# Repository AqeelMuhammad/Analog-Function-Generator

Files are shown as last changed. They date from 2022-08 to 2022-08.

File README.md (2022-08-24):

# Analog-Function-Generator

* Function generators are commonly used to generate analog waveforms (like sine waves, square waves, sawtooth waves etc.) in a variety of applications, such as sweep generation, AM/FM generation and Phase Locked Loops (PLLs). 
* Some of the popular analog ICs used in the past were MAX038, XR2206 and NTE864. Now they have been mostly replaced with chips using Direct Digital Synthesis (AD9850 DDS signal generator module). 
* Function generators can usually change their waveform frequency precisely among a wide range of values (0.1 Hz to 1 MHz). Furthermore, they can even change their amplitudes and average DC values. In some sensitive applications, capability of a function generator to create a clean, noise-free waveform becomes 
extremely important. 
* This repo is about an analog circuit using transistors and op-amps which can generate sine waves, square waves (with variable duty cycle), sawtooth waves and triangular waves.
* The project was done by a team of 4 undergraduates at the Department of Electronic and Telecommunication Engineering, University of Moratuwa, Sri Lanka for UOM's EN2090 - Laboratory Practice - II module.

### Contributors

1. [Muhammad Aqeel](https://github.com/AqeelMuhammad)
1. [yomali lokugama](https://github.com/lokugama-vyn)
1. [Tharushi Pinimuthu](https://github.com/)
1. [Sanduni Kaushalya](https://github.com/)

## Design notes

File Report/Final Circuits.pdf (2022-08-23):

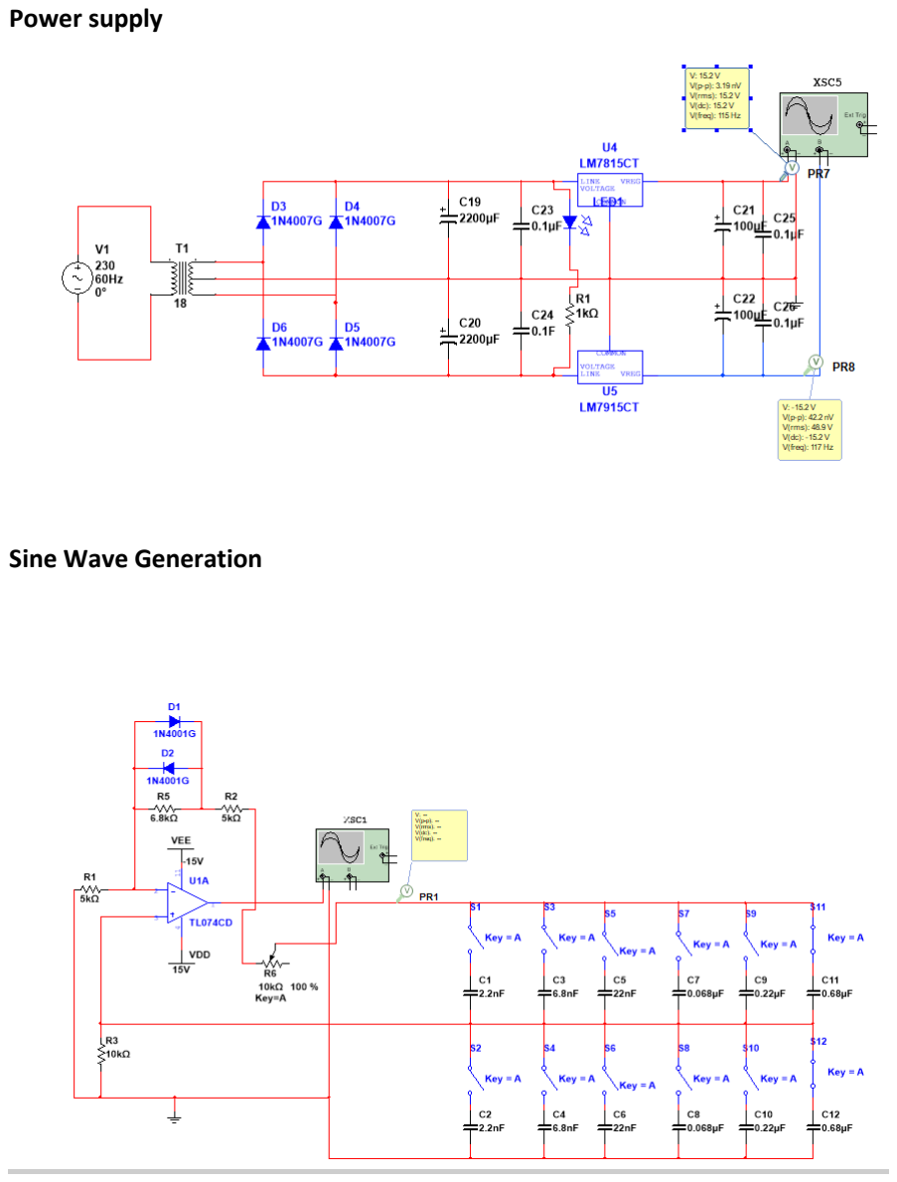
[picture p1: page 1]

Power supply

Sine Wave Generation

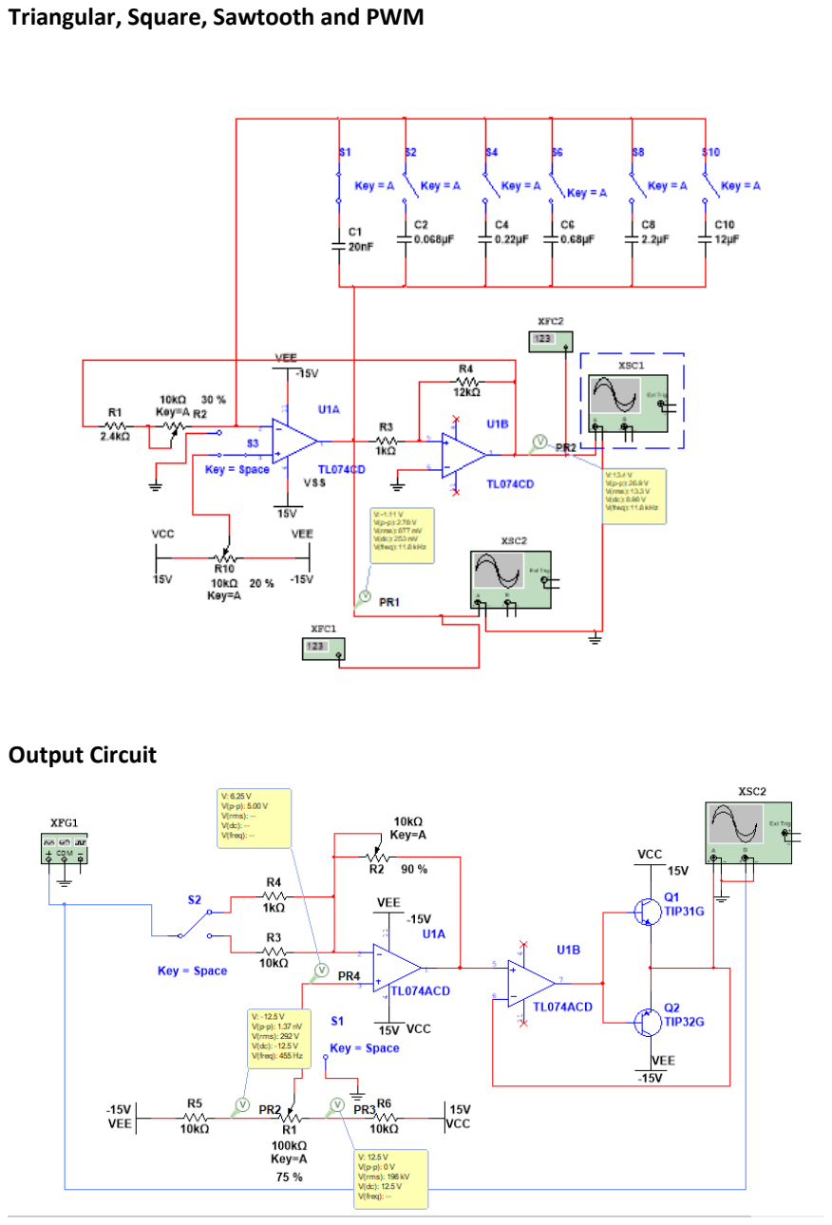
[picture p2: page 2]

Triangular, Square, Sawtooth and PWM

Output Circuit

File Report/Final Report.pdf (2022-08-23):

Department of Electronic and Telecommunication Engineering

University of Moratuwa

EN – 2090 Laboratory practice II

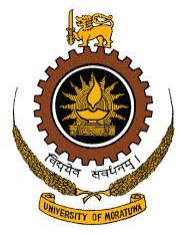
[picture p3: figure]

## ANALOG FUNCTION GENERATOR

GROUP 20

AQEEL T.M. | 180039C
KAUSHALYA P.A.S. | 180320F
LOKUGAMA V.Y.N. | 180359G
PATHIRANA T.P.W. | 180453N

This is submitted as a partial fulfillment for the module EN 2090: Laboratory Practice II Department of Electronic and Telecommunication Engineering University of Moratuwa

ABSTRACT

Function generator is an electronic device which generates various types of electrical waveforms over a broad range of frequencies. These devices can be used to generate waves with variable frequencies, amplitudes, offsets, and duty cycles for various experimental design purposes. Today most of the function generators are made using digital electronics components and these devices costs around $1000. This report talks about the overview of a signal generator, how to generate function using analog electronics, and changing its characteristics like waveform, modulation, frequency, and amplitude voltage.

CONTENTS

1. INTRODUCTION ------------------------------------------------------------------------------------------4
2. ELECTRONIC DESIGN ----------------------------------------------------------------------------------4

2.1 Design Specifications --------------------------------------------------------------------------------4

2.2 Waveform Generation-------------------------------------------------------------------------------4

2.2.1 Square Wave--------------------------------------------------------------------------------- 4

2.2.2 Triangular Wave---------------------------------------------------------------------------- 5

2.2.3 Sawtooth Wave ------------------------------------------------------------------------------ 5

2.2.4 PWM Wave ---------------------------------------------------------------------------------- 5

2.2.5 Sine Wave ------------------------------------------------------------------------------------ 6

2.3 Other Circuits -----------------------------------------------------------------------------------------6

2.3.1 DC shift --------------------------------------------------------------------------------------- 6

2.3.2 Push Pull Amplifier------------------------------------------------------------------------- 6

Class A -----------------------------------------------------------------------------------------------------6

Class B -----------------------------------------------------------------------------------------------------6

Class AB ---------------------------------------------------------------------------------------------------7

2.3.3 Power Supply Circuit ---------------------------------------------------------------------- 7

3. SIMULATIONS---------------------------------------------------------------------------------------------7

3.1 Sine Wave-----------------------------------------------------------------------------------------------7

3.2 Triangular, Square, Sawtooth, & PWM--------------------------------------------------------8

3.3 DC Shift & Amplification --------------------------------------------------------------------------8

4. CALCULATIONS ------------------------------------------------------------------------------------------9

4.1 Triangular, Sawtooth and Square Wave Calculation---------------------------------------9

4.2 Sine Wave Calculation ------------------------------------------------------------------------------9

4.2.1 Wein Bridge Oscillator ------------------------------------------------------------------ 10

5. OP AMP SELECTION----------------------------------------------------------------------------------- 11
6. ROTARY SWITCH -------------------------------------------------------------------------------------- 11
7. SCHEMATIC DESIGNS-------------------------------------------------------------------------------- 12
8. LAYOUTS-------------------------------------------------------------------------------------------------- 12
9. REFERENCES -------------------------------------------------------------------------------------------- 14

### 1. INTRODUCTION

The | function | generator | can | generate
square, triangle, sawtooth, PWM and sine waveforms. Function generators can usually change their waveform frequency precisely among a wide range of values. Furthermore, they can even change their amplitudes and average DC values.

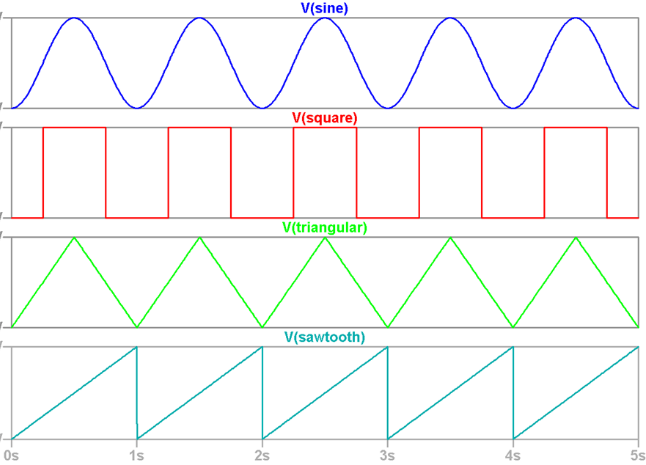
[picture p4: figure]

Figure 1 - Different types of waveforms

Some applications of function generator are sweep generation, AM/FM generation and Phase Locked Loops (PLLs).

In this report, we describe how we are going to build an analog circuit using transistors and op-amps and how we are going to change the frequencies and the amplitudes of the waveforms.

### 2. ELECTRONIC DESIGN

### 2.1 Design Specifications

In this project, we will fulfill the following specifications.

1. Function generator should be able generate sine, square, pulse width modulation, sawtooth, and triangular waves.
2. The output amplitude should be variable from 0V to 10V.
3. The output frequency should be variable from 20 Hz to 20000 Hz.
4. It should be able to drive at least a 50 Ohm load without significant waveform distortion or amplitude reduction.
5. PWM waveform should have a variable pulse width (1% to 99%).
6. The function generator should be able to give a DC shift to the waves.

### 2.2 Waveform Generation

2.2.1 Square Wave

The square wave as well as the triangular waves are combined together, which means that the output of one circuit acts as input of the other. The square wave was just the result of the comparator property of the Op-Amp used. The triangular wave was sent through the inverting input and a threshold voltage was set with the help of a feedback resistor and an input resistor. To change the frequency of the wave we are going to use a potentiometer in the place of R3 with a fixed resistor.

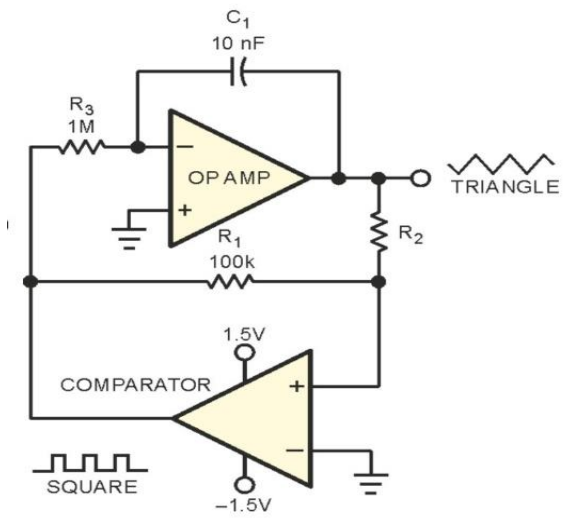
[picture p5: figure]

Figure 2 - Square & triangular waveform generating circuit

The solitary-comparator circuit uses a relaxation oscillator approach with the triangle approximation assuming an RC nature and by adding an integrator improves the triangle approximation. The circuit includes a hysteretic-feedback path as well as an RC or integrator feedback path comprising R3 and C1. The hysteretic-feedback path keeps changing the direction of the RC integrator and setting the new target voltage, and the RC integrator sets the rate of change toward the new target.

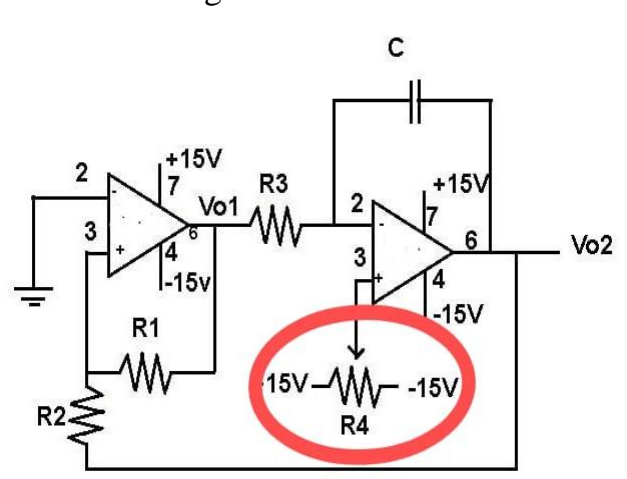
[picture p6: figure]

In the above circuit, we can calculate the frequency using the following equation.

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
(4 × R3 × C1)

So, we are planning to change the frequency of the waveform using R3 resistor and C1 capacitor fixing the resistors R1 & R2.

2.2.2 Triangular Wave

As shown in the figure 2 the integral Op-Amp is used in generate triangular wave from square wave. The square wave output was input to the Op-Amp with a capacitance and an input resistor value which makes the Op-Amp to act as a desired integrator. The frequency of the wave can be changed in the same way by changing the frequency of the square wave.

Figure 4- integrator

2.2.3 Sawtooth Wave

We plan to generate the sawtooth waveform from the same output pin where the triangular wave is generated. The only change made in the circuit is, if the non-inverting input of the

Op-Amp is set to ground triangular wave is generated whereas if that is set to a potentiometer with a varying voltage a sawtooth waveform is generated. The modification is given below.

2.2.4 PWM Wave

We plan to generate the PWM waveform from the triangular wave. A comparator is used to generate different duty cycles of PWM. We plan to give a reference voltage to inverting input at the same time we give the triangular wave to non-inverting input. If instantaneous voltage of the triangular wave is greater than the reference, output will be +Vs if less than reference, output will be -Vs. By changing the reference-voltage we give, we can change the duty cycle. For changing reference-voltage we plan to use a voltage divider circuit with a potentiometer.

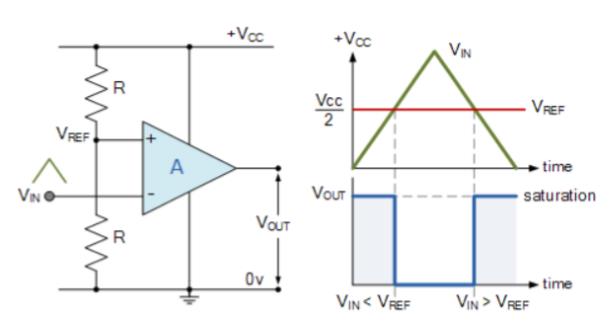
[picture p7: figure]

Figure 5 Comparator Circuit

Figure 3 - Sawtooth generation circuit

2.2.5 Sine Wave

To obtain the sine waveform, we plan to use the Wein bridge oscillator circuit. The circuit is stabilized for controlling the gain. The Wein bridge oscillator has two capacitors, of which the values should be equal to each other. The frequency range is selected using these capacitors, while the variable resistor is used to obtain a specific frequency within the selected range.

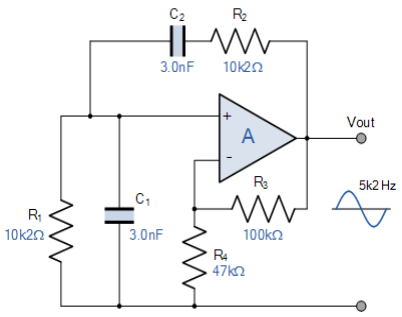
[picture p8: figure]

Figure 6 - Wein Bridge Oscillator

Hence, here is a frequency point where the maximum Vout can be occurred and it is known as oscillator resonance frequency(fr) At fr, Xc = R and phase difference between input and output is zero.

The circuit contains two RC pairs where in one R & C are in series and in the other the R & C are in parallel. Both the series and parallel RC combinations combined together to make a frequency dependent voltage divider. The output of the operational amplifier (op amp) is fed back to both the inputs of the op amp, through a feedback resistor to the inverting input and through the series RC combination to the non-inverting input. The whole combination generates a sine wave at the resonance frequency(fr), given by the equation,

fr =

1
2πRC

Fr -resonant frequency
R-Resistance
C- Capacitance
In this circuit, in series and parallel RC
combinations, | two | resistors | and | two
capacitors have to be of the same value.

### 2.3 Other Circuits

2.3.1 DC shift

We plan to add a DC offset to the generated waveform using an Op-Amp circuit. It is an inverting amplifier circuit. Input and a DC voltage is given to the inverting pin of the Op-Amp. DC voltage is controlled by the potentiometer.

2.3.2 Push Pull Amplifier

Class A
- One transistor always remains ON
- Distortions are minimum
- Amplified efficiency is 30%
- Same amount of load current to flow through even when there is no signal.

Class B
- The two identical transistors are connected in such a way that each transistor is operating per each half cycle.
- Efficiency is about 50%, greater than of class A
- Q point of the transistor is located at its cut off region

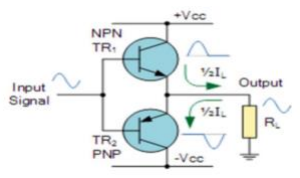
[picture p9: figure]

Figure 7 - Class B

Class AB
- The efficiency is about 50%
- Conduction angle is between 180 and 360
- Low crossover distortion
- In here both transistors are on between -0.7v and 0.7v
- High linearity like class A amplifier

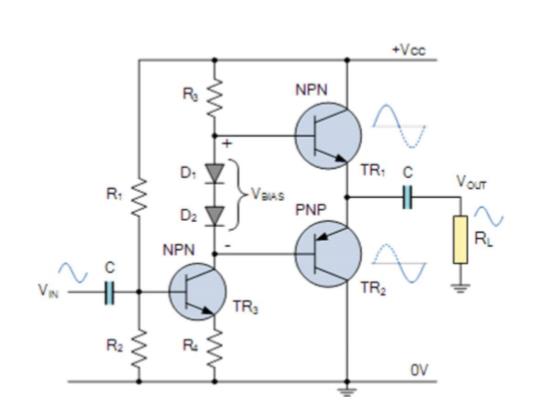
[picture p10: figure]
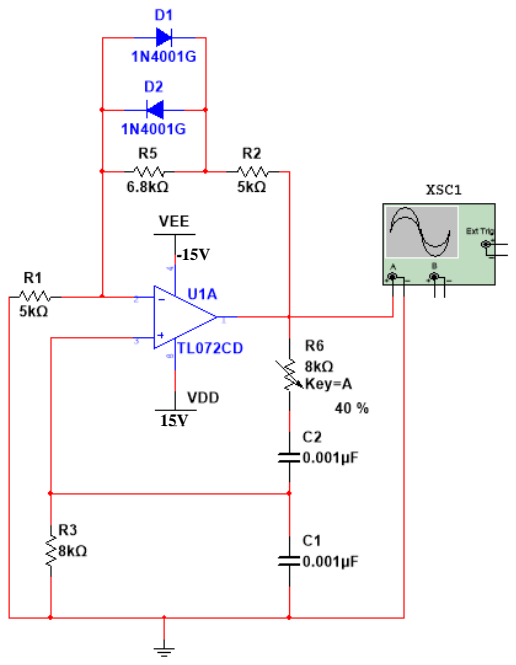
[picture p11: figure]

Figure 8 - Class AB

We are going to design the amplifier circuit in three stages.

Inverting amplifier stage -To obtain a variable amplitude
Voltage buffer stage - To maintain the stability
Push pull amplifier stage – To produce high current

2.3.3 Power Supply Circuit

We have to create +12V and -12V DC power supply to perform our expected task. Since the function generator is a laboratory equipment and it is used for a long time, we planned to supply the voltage using an AC power supply. We are going to use a stepdown transformer of 15V, a rectifier bridge and LM7812 and LM7912 regulators for this purpose.

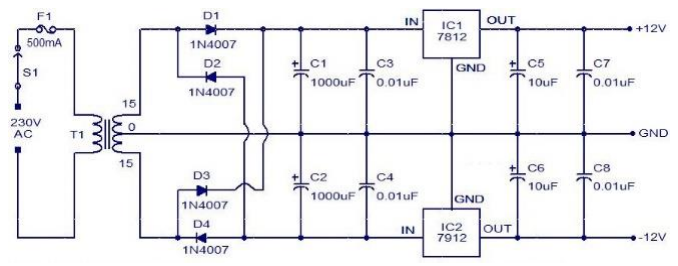
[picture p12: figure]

Figure 9 - Power Supply Circuit

### 3. SIMULATIONS

### 3.1 Sine Wave

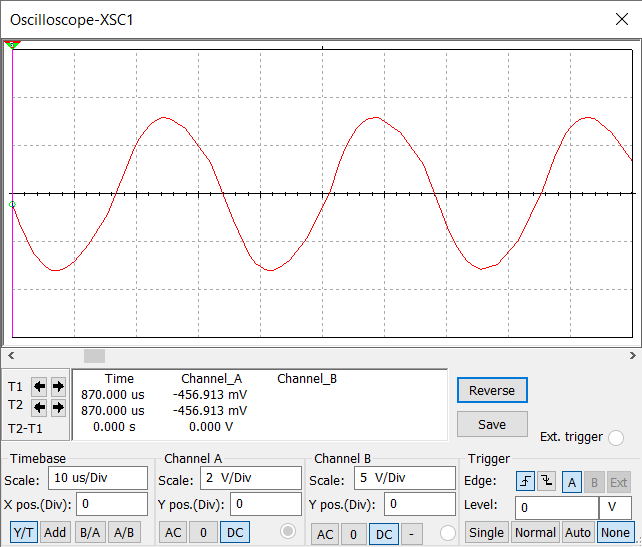
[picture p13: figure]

Figure 10 - Sine Wave Simulation

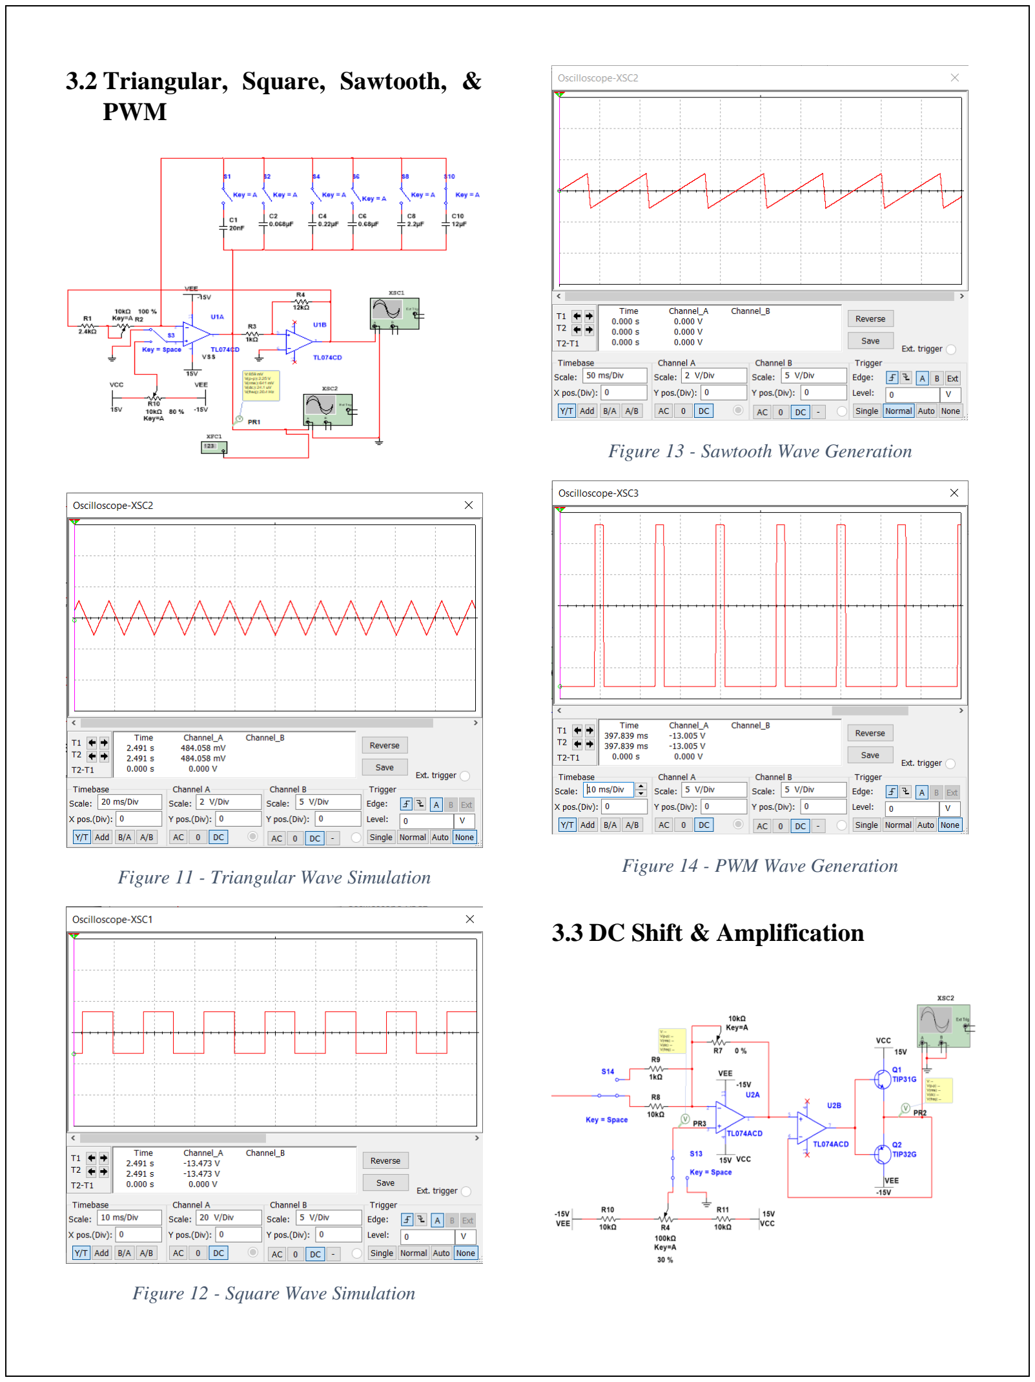
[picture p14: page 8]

### 3.2 Triangular, Square, Sawtooth, &

PWM

Figure 11 - Triangular Wave Simulation

Figure 12 - Square Wave Simulation

Figure 13 - Sawtooth Wave Generation

Figure 14 - PWM Wave Generation

### 3.3 DC Shift & Amplification

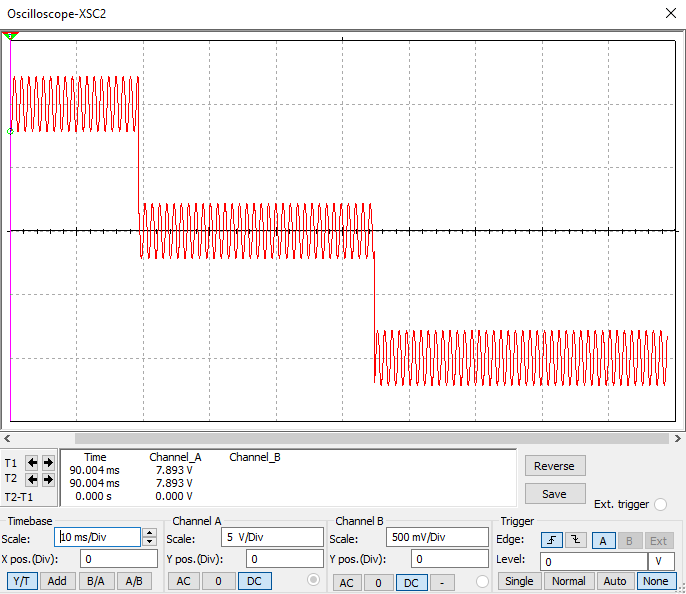
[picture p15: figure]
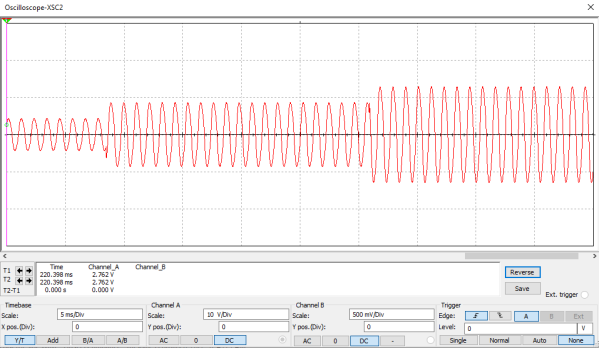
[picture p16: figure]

Figure 15 - shift Simulation

### 4. CALCULATIONS

### 4.1 Triangular, Sawtooth and Square

Wave Calculation

- For 20Hz,
R3 = 6.2kΩ | R2 = 2.4kΩ
R4 = 1kΩ | R5 = 12kΩ

20 =

12
1

×

| 1
4×(6200+2400)×C1

C1 = 17.44 µF

- For 20kHz,
R3 = 0kΩ | R2 = 2.4kΩ
R4 = 1kΩ | R5 = 12kΩ

20000 =

12
1

×

| 1
| 4×(2400)×C1

C1 = 0.0625 µF

### 4.2 Sine Wave Calculation

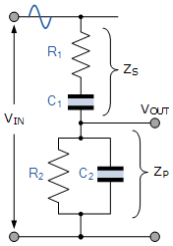
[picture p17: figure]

Figure 17 -Sine Wave Generation Circuit

For example, we can take R1=R2=12kΩ, C1=C2=3.9nF and the supply frequency f=3.4kHz.

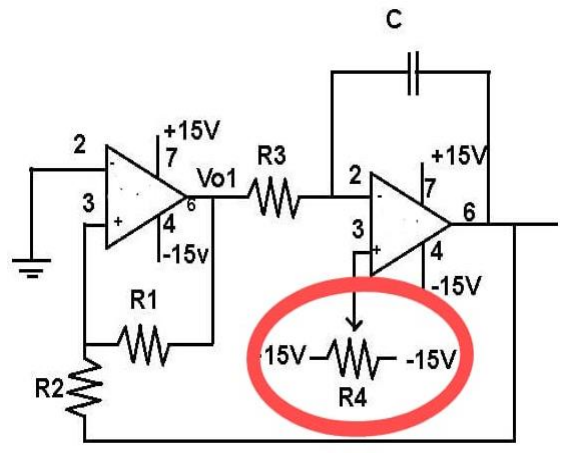
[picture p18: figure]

Figure 16 -Wave Form Generation Circuit

- For Series Combination

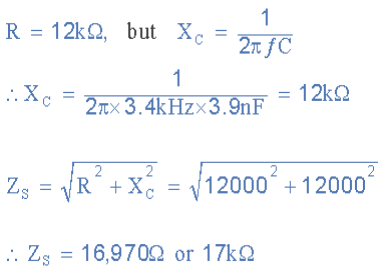
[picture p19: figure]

- For Parallel Combination

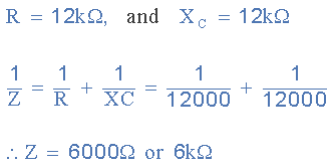
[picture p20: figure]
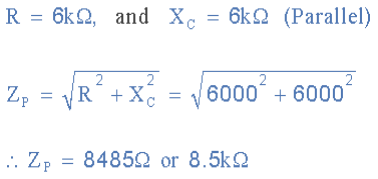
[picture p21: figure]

- Z Out of Voltage Divider
- Then,

Vout = Zout x Vin

Vout =

1
3

x Vin

Above values are used to show how 1/3 comes and We will change the resistor values for the circuit while we will be testing the circuits according to the results.

4.2.1 Wein Bridge Oscillator

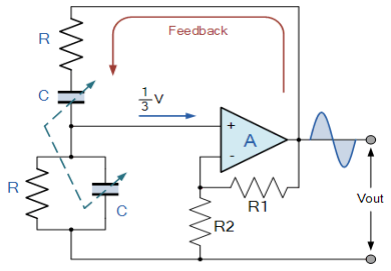
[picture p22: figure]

Figure 18- Wein Bridge Oscillator

[

To get the oscillation output, Av ≥ 3

fr =

1
2πRC

We have to vary the frequency from 20Hz-20000kHz. We have choose C1,C2 as 1nF to achieve maximum 20kHz frequency.

R =

1
2π × 20kHz × 1nF
= 7.957kΩ ≈ 8kΩ

We have choose C1,C2 value as 1uF to achieve minimum 20Hz frequency.

f =

1
2π × 8kHz × 1μF

= 19.89Hz ≈ 20Hz

To begin the sinusoidal oscillation Av ≥ 3; We Assumed R4 as 5kΩ. Then,

Output voltage gain of non-inverting amplifier (Av) = 1 +

R1
R2

=

Vout

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
R3 ≥ 10kΩ

We need to use some methods to be stabilizing the amplitude of the oscillations. If the voltage gain of the amplifier is too small the desired oscillation will decay and stop. If it is too large the output will saturate to the value of the supply rails and distort. We have used feedback diodes to stabilization of amplitude.

### 5. OP AMP SELECTION

When choosing an op amp, we must consider the main requirements. They are,

- Input offset voltage
- Input impedance
- Input leakage current
- Common mode rejection ratio
- Open loop gain
- Bandwidth
- Maximum output slew rate
- Output source and sink current limits
- Noise figure

But needed requirements differ from application to application. We want to find an op amp with better features for the function generator circuits. We choose TL072 and LM741 to generate waveforms.

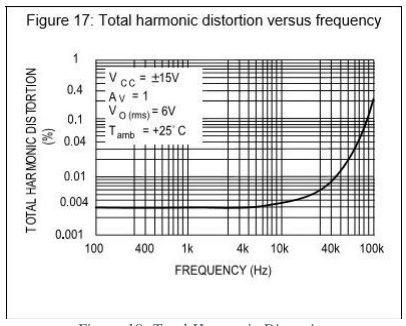
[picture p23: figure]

These two figures show how the noise input voltage and harmonic distortions change with respect to the frequency. Hence, both noise effect and harmonic distortions increase when frequency is increased. We have to change the frequency from 20Hz-20000Hz, and it is suitable to stop all scenarios that can generate noise as well as harmonic distortions. We choose TL072 on the fact of low noise and low harmonic distortions. There are number of noise sources within an op amp such as resistor noise, current noise, and KT/C noise. Reduction of resistors as well as covering the non-used pins of op-amps may help to reduce the noise effects and harmonic distortions.

### 6. ROTARY SWITCH

For the selection of different frequencies of the waveforms, and for the selection of the waveform. we are going to use rotary switches in our design. A rotary switch is a switch in which the contacts are changed when the spindle is rotated in either a clockwise or an anticlockwise direction. We

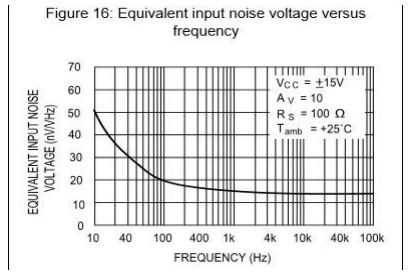
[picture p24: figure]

Figure 20 - Equivalent Input Noise Voltage

Figure 19 -Total Harmonic Distortion


are going to use 1 pole 12-way rotary switch for this purpose, and we can change the frequency values by changing the capacitor values.

Figure 21 -Rotary Switch

### 7. SCHEMATIC DESIGNS

### 8. LAYOUTS

Figure 22 – Sine Wave Schematic

Figure 23 – Sawtooth, Triangular, Square, & PWM Wave Schematic

Figure 24 – Output Circuit Schematic

Figure 25 – Power Supply Circuit Schematic

Figure 26 – Sawtooth, Triangular, Square, & PWM Wave 3D


Figure 28 – Sine Wave Layout

Figure 27 – Sawtooth, Triangular, Square, & PWM Wave 3D

Figure 29 – Sine Wave 3D

Figure 30 – Output Circuit Layout

Figure 31 – Output Circuit 3D

Figure 32 – Power Supply Circuit Layout

Figure 33 – Power Supply Circuit 3D

### 9. REFERENCES

https://www.instructables.com/id/Function-Generator/ (https://www.instructables.com/id/Function-Generator/)

https://www.watelectronics.com/squarewave-generator-circuit-using-op-amp/ (https://www.watelectronics.com/square-wave-generator-circuit-using-op-amp/)

https://www.radiolocman.com/shem/schematics.html?di=277157 (https://www.radiolocman.com/shem/schematics.html?di=277157)

http://www.circuitsgallery.com/2012/04/tria ngul ar-wave-generator-using-op-amp.html (http://www.circuitsgallery.com/2012/04/triangul%20ar-wave-generator-using-op-amp.html)

https://www.maximintegrated.com/en/design/technical-documents/appnotes/3/3846.html (https://www.maximintegrated.com/en/design/technical-documents/app-notes/3/3846.html)

https://www.electronicstutorials.ws/opamp/op-amp-comparator.html (https://www.electronics-tutorials.ws/opamp/op-amp-comparator.html)

https://electronics.stackexchange.com/questions/370739/how-to-add-dc-offset-and-gainto-a-given-signal (https://electronics.stackexchange.com/questions/370739/how-to-add-dc-offset-and-gain-to-a-given-signal)



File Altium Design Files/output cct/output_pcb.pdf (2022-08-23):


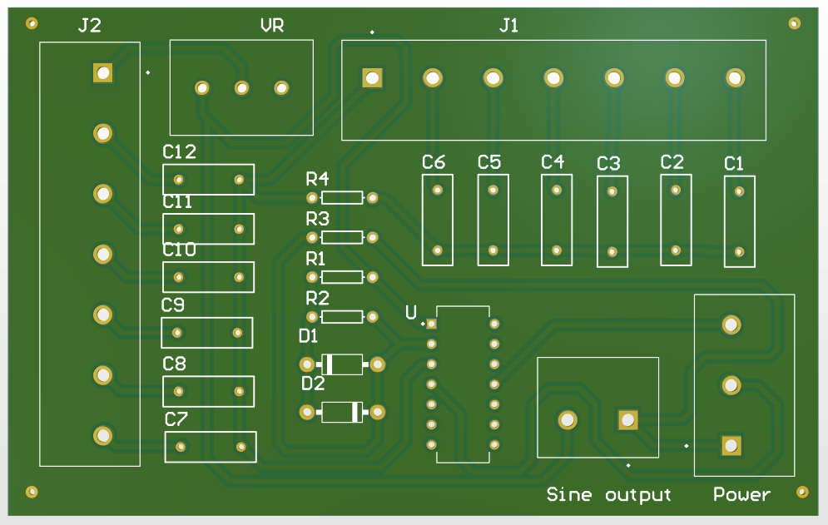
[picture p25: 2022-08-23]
Images/Altium Designs/sine 3d.PNG

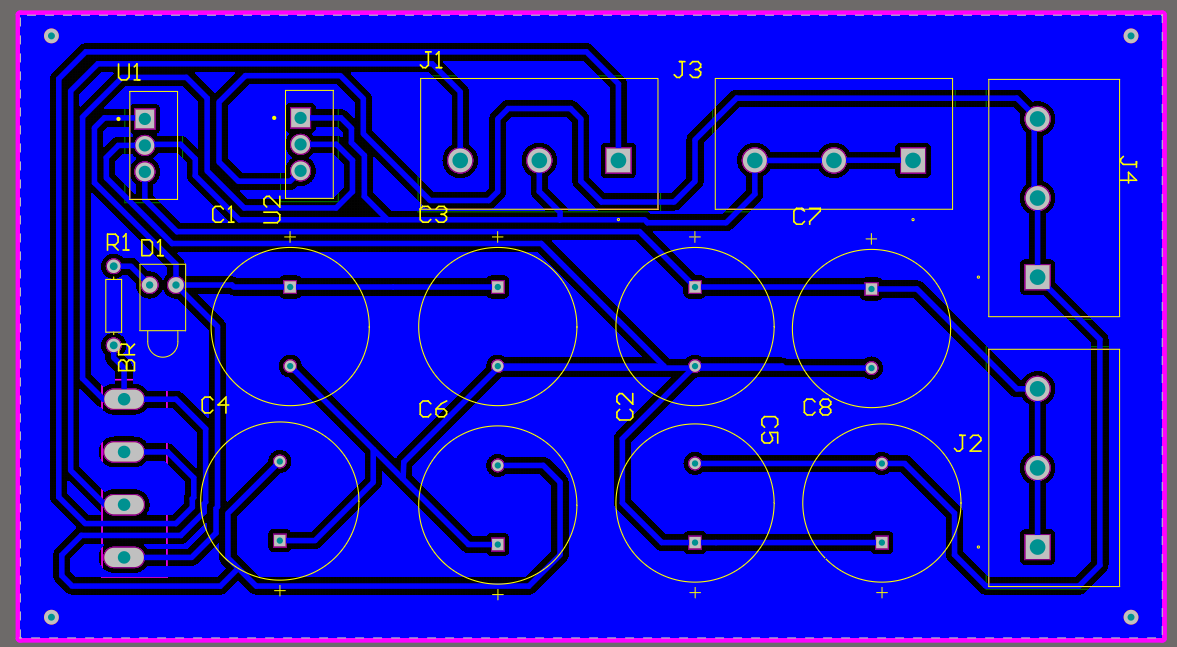
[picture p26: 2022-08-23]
Images/Altium Designs/power supply.PNG

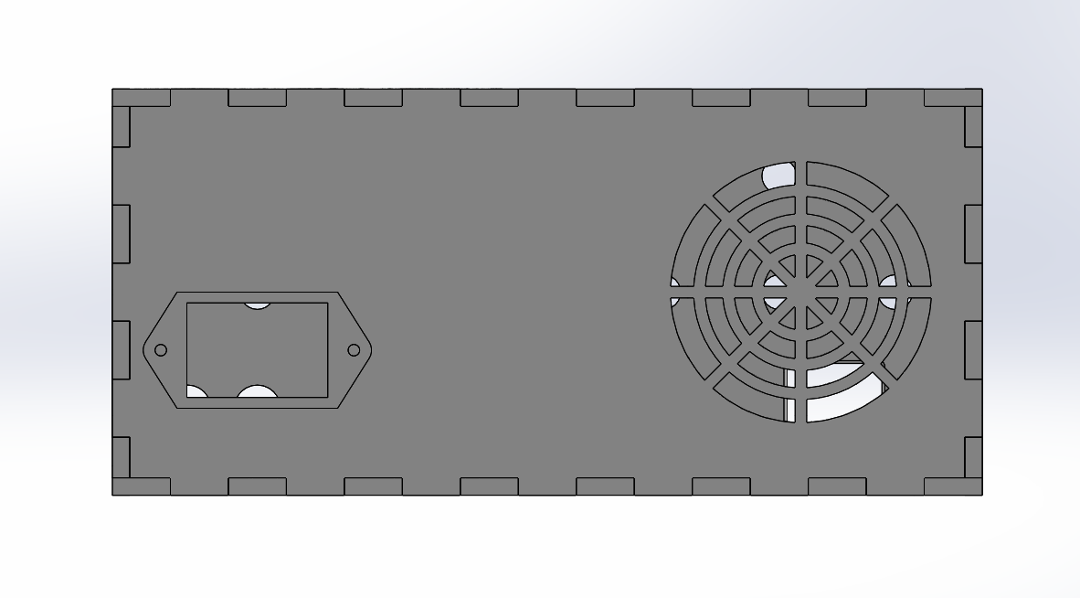
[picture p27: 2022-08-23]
Images/SolidWorks Designs/Final/Back.png

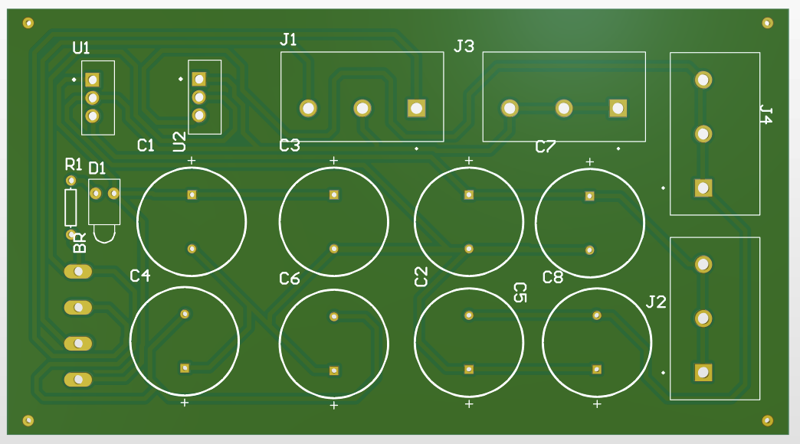
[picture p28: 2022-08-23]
Images/Altium Designs/power supply 3d.PNG

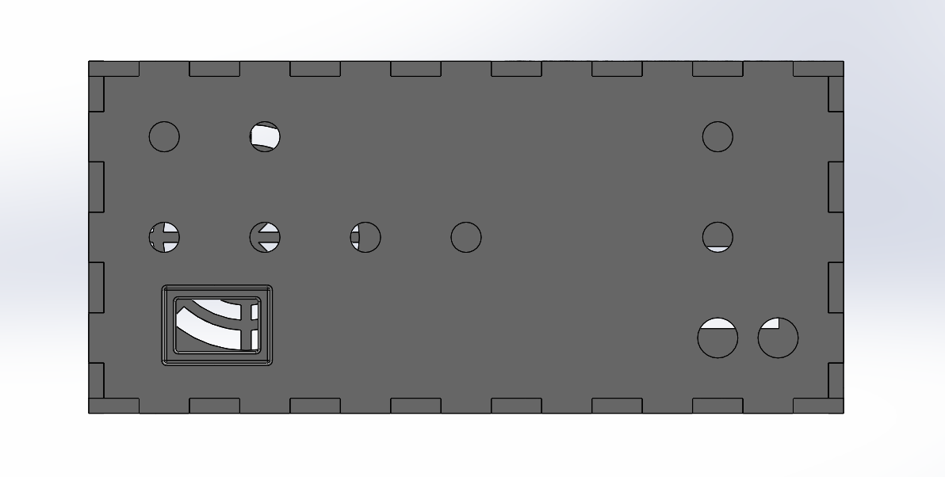
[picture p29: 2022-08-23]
Images/SolidWorks Designs/Final/Front.png

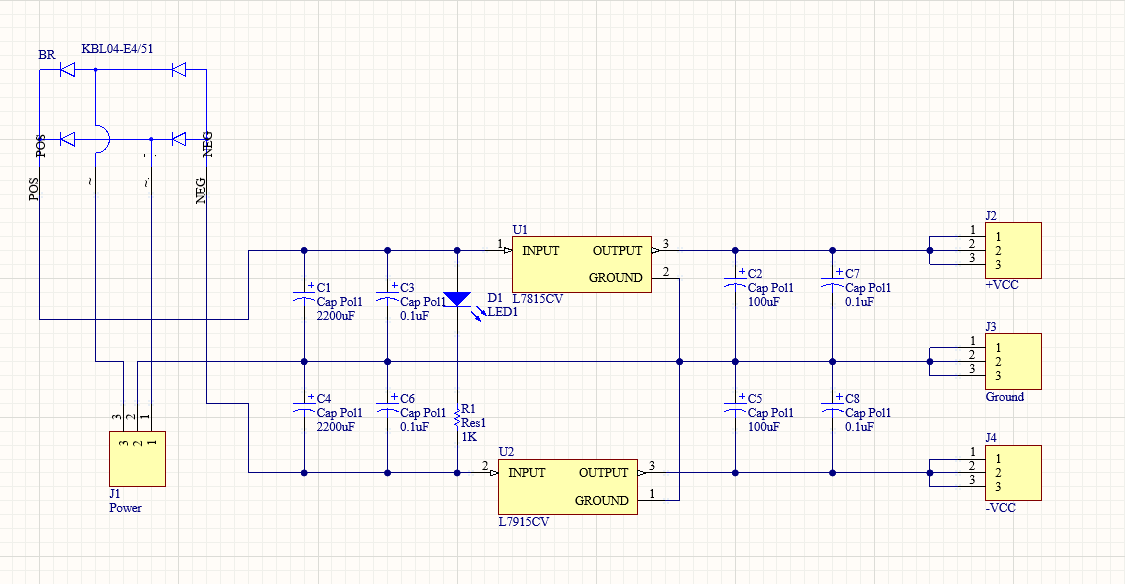
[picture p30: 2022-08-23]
Images/Altium Designs/power supply sch.PNG

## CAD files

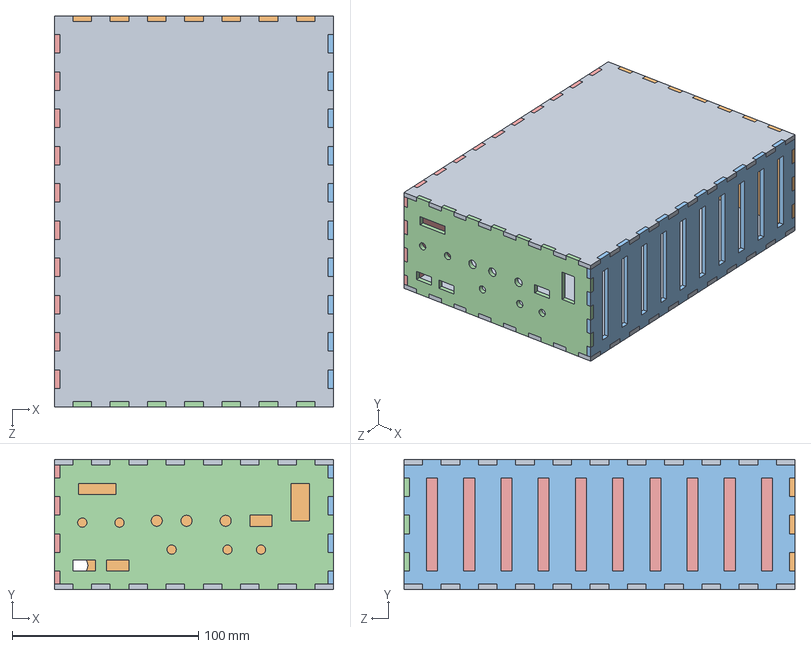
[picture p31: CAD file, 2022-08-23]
SolidWork Design Files/Assem2.SLDASM
150.0 x 70.0 x 210.0 mm

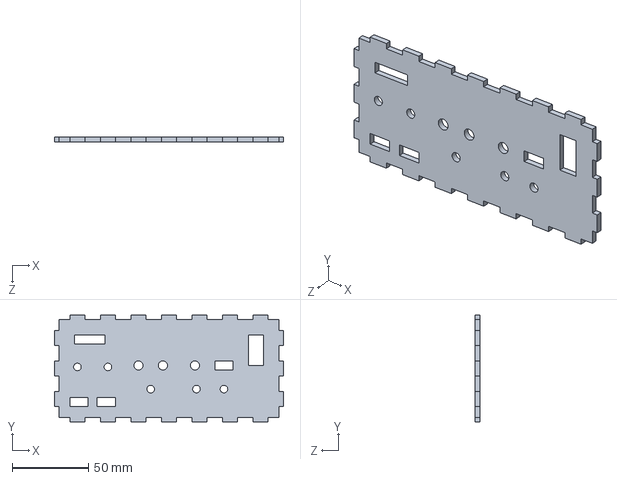
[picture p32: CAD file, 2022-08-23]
SolidWork Design Files/Part11.SLDPRT
150.0 x 70.0 x 3.00 mm

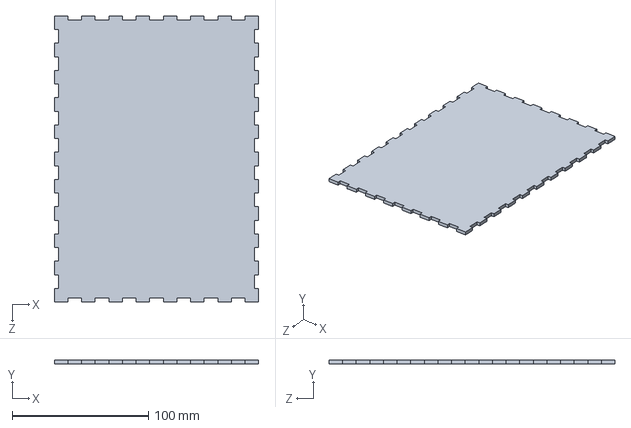
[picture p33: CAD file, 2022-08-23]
SolidWork Design Files/Part2.SLDPRT
150.0 x 3.00 x 210.0 mm

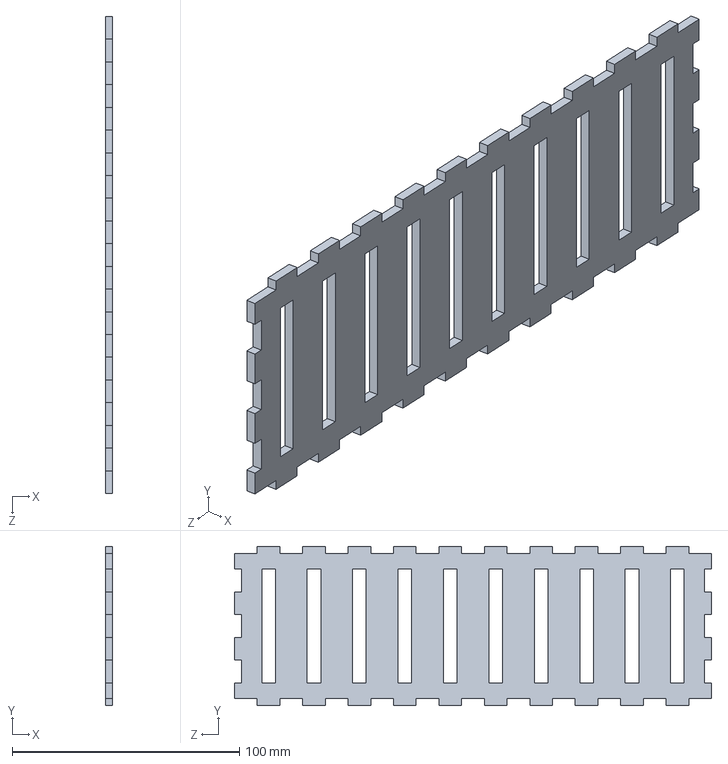
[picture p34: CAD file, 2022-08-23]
SolidWork Design Files/Part3.SLDPRT
3.00 x 70.0 x 210.0 mm

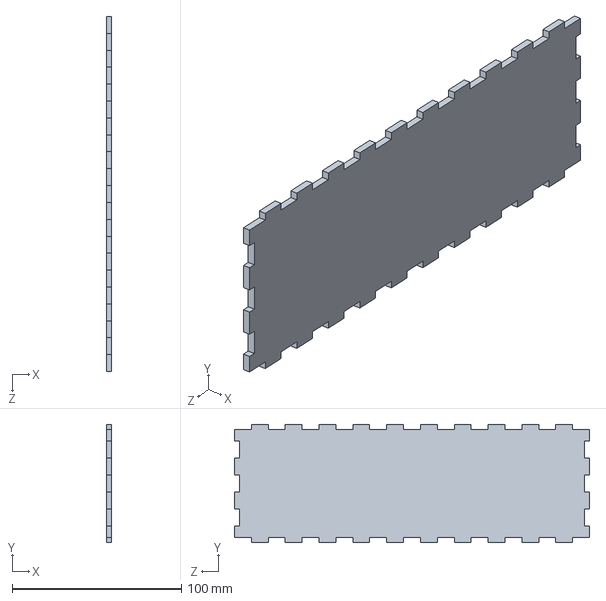
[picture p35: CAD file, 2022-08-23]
SolidWork Design Files/Part33.SLDPRT
3.00 x 70.0 x 210.0 mm

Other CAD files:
SolidWork Design Files/Part1.SLDPRT

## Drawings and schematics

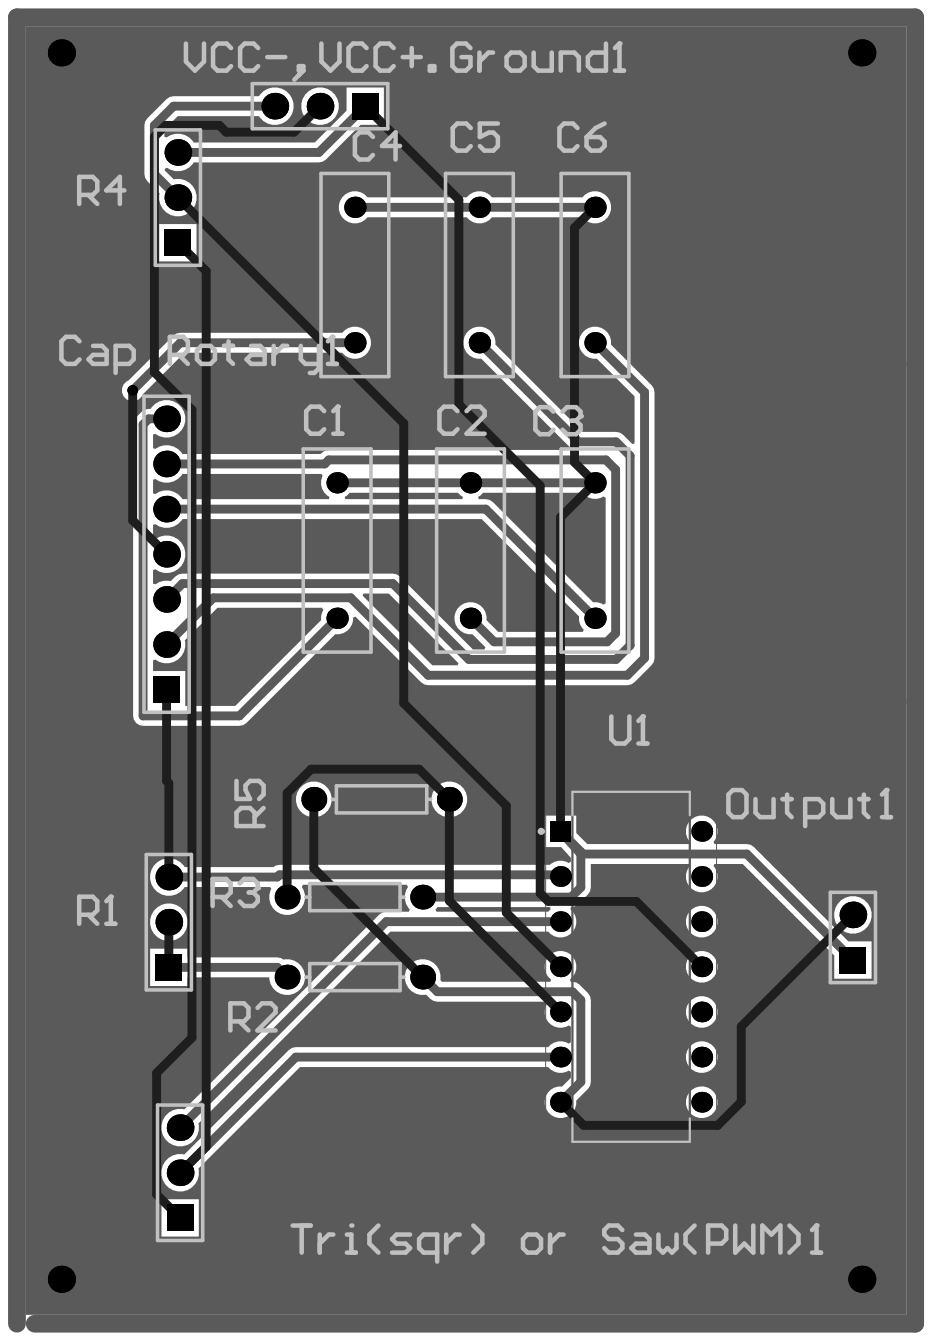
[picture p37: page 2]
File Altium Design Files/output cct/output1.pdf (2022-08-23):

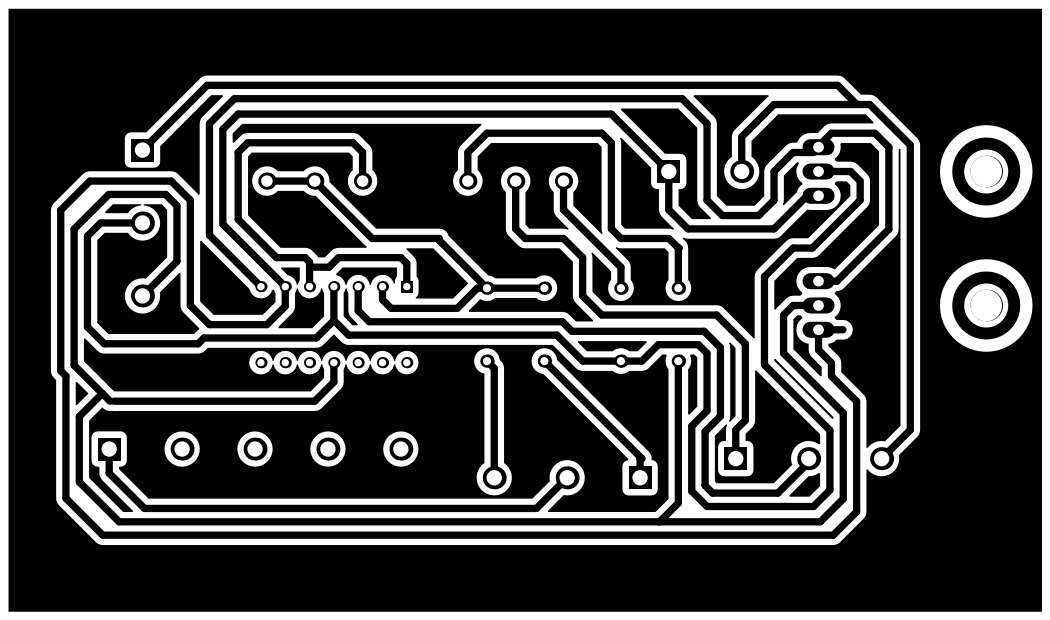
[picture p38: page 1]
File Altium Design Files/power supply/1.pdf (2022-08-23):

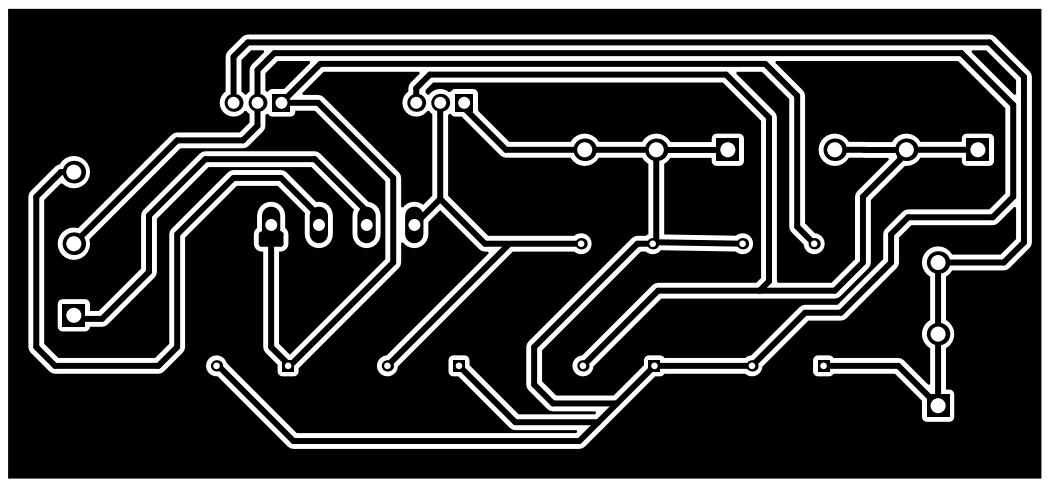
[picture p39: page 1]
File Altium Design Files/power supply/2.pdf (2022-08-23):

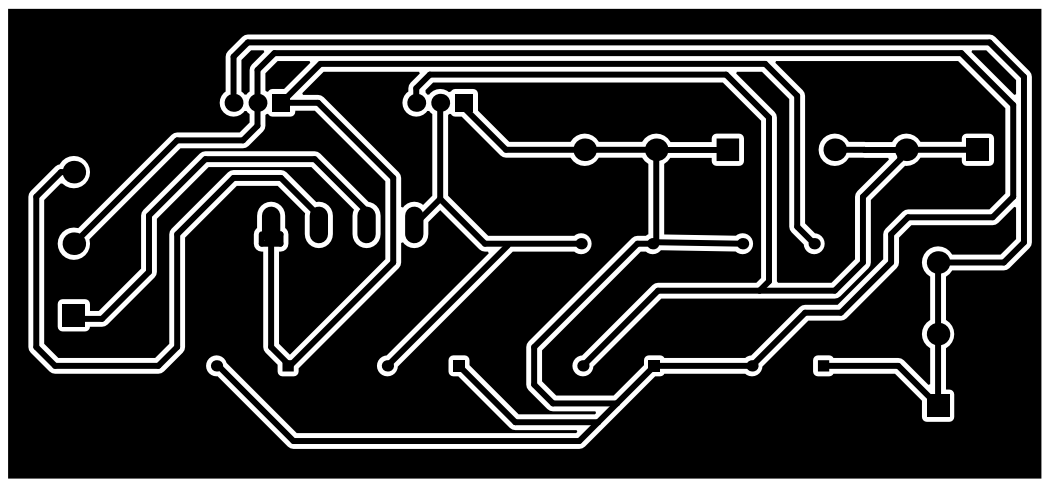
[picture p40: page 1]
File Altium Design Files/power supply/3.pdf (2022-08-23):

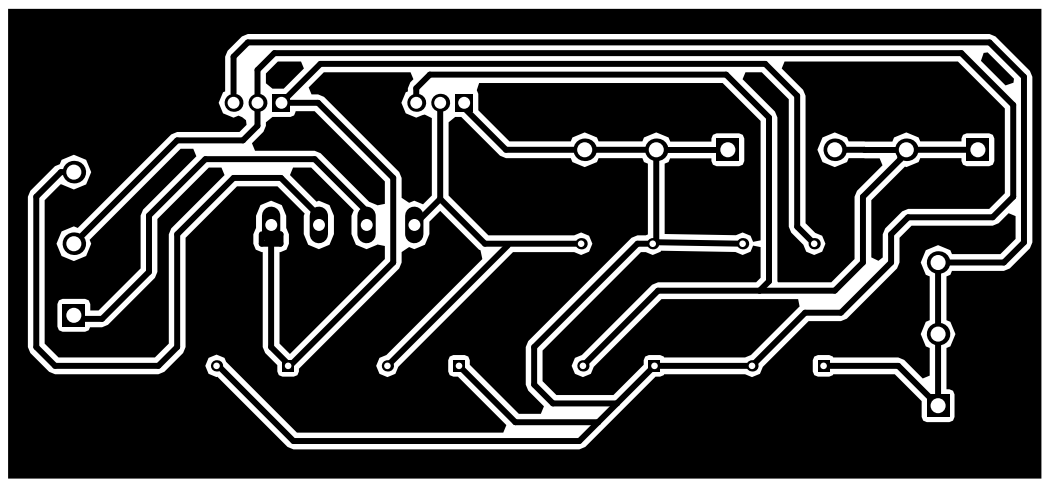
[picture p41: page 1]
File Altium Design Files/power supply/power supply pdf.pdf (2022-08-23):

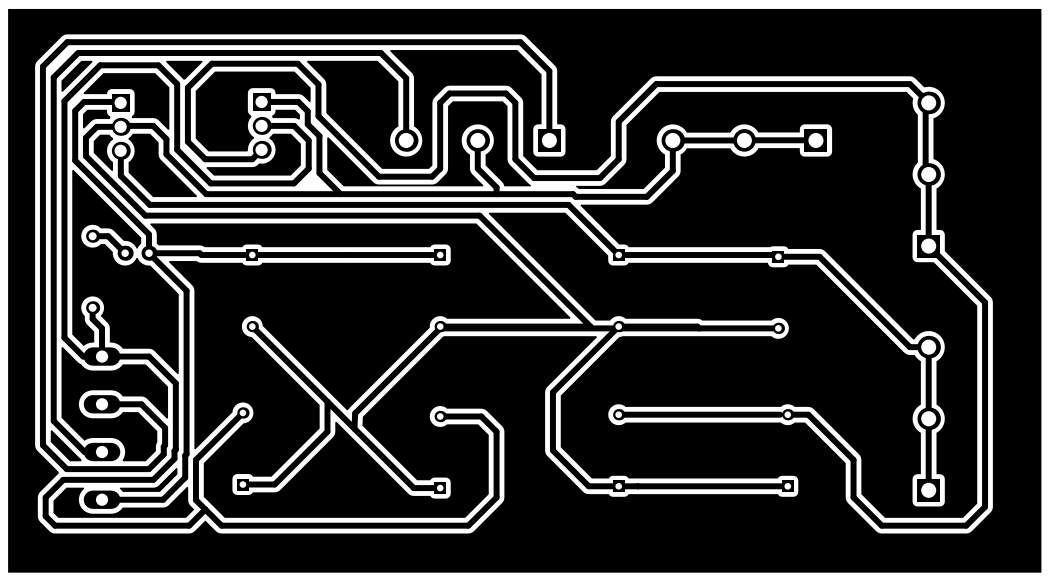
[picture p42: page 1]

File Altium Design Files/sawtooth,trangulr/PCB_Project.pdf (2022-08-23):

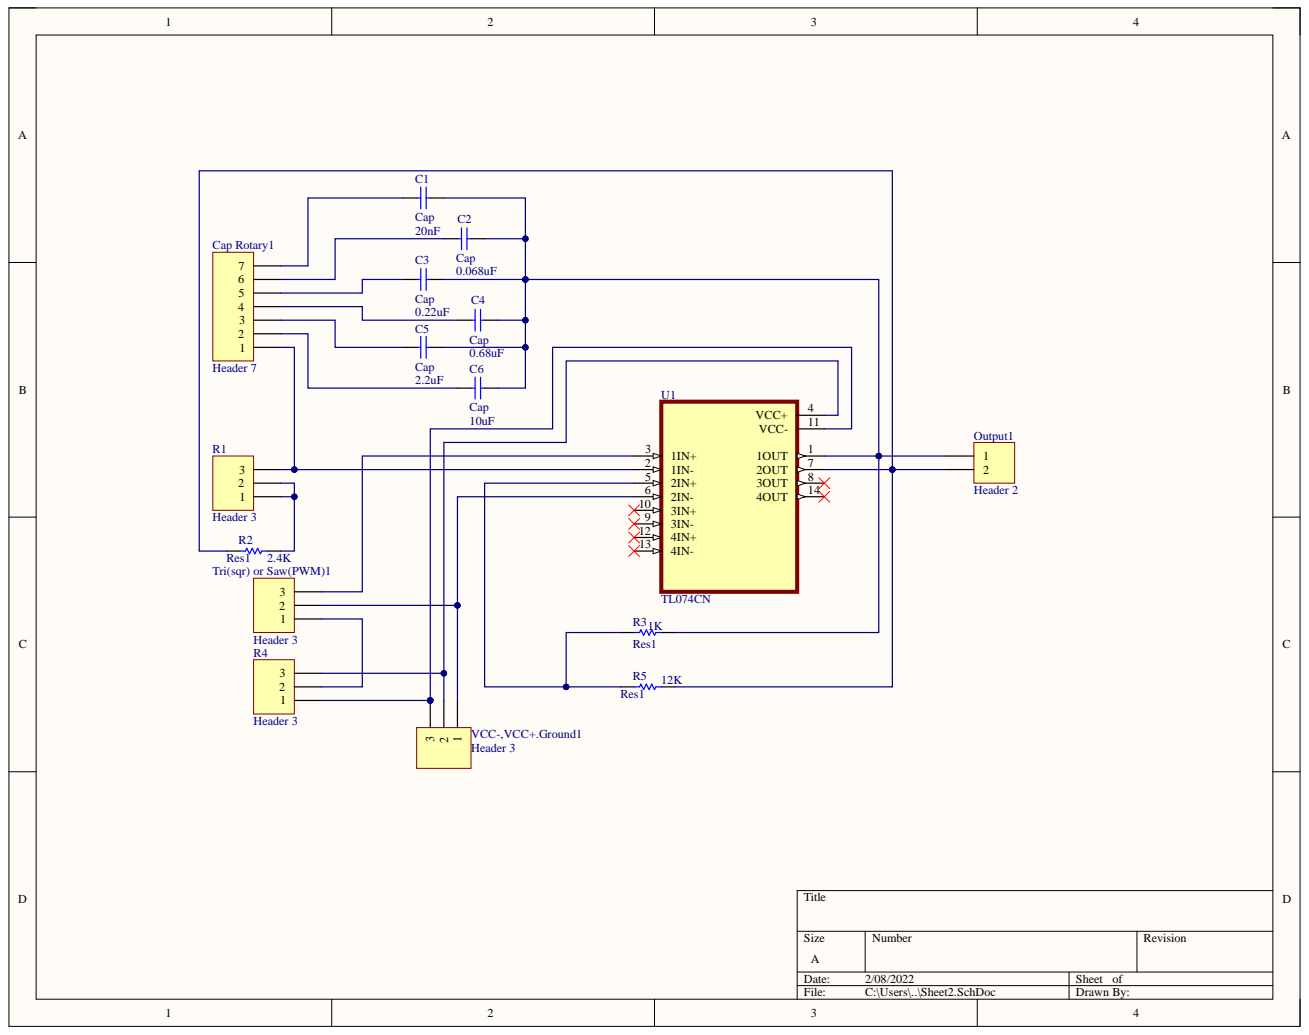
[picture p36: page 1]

Cap C4
0.22uF
C5

Res1
Tri(sqr) or Saw(PWM)1
